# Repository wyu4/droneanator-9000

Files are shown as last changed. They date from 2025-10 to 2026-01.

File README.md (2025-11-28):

# Droneanator 9000

The "Droneanator 9000" is an autonomous unmanned aerial vehicle (UAV). It will aid remote communities worldwide through long-range autonomous supply missions, improving quality of life for those living in these communities. Our clients will include disaster relief agencies, charity organisations, government agencies, etc. See the HRS document for more information.

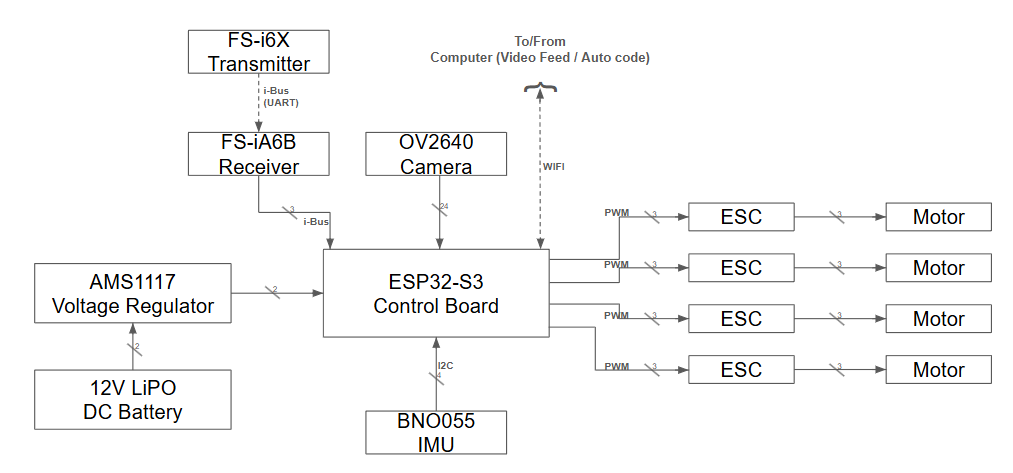
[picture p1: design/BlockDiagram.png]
block diagram


## IDE

This project uses the PlatformIO extension in VSCode.

## Libraries

| **Name** | **Link** |
| --- | --- |
| IBusBM | https://github.com/bmellink/IBusBM |
| BNO055 | https://github.com/adafruit/Adafruit_BNO055 |

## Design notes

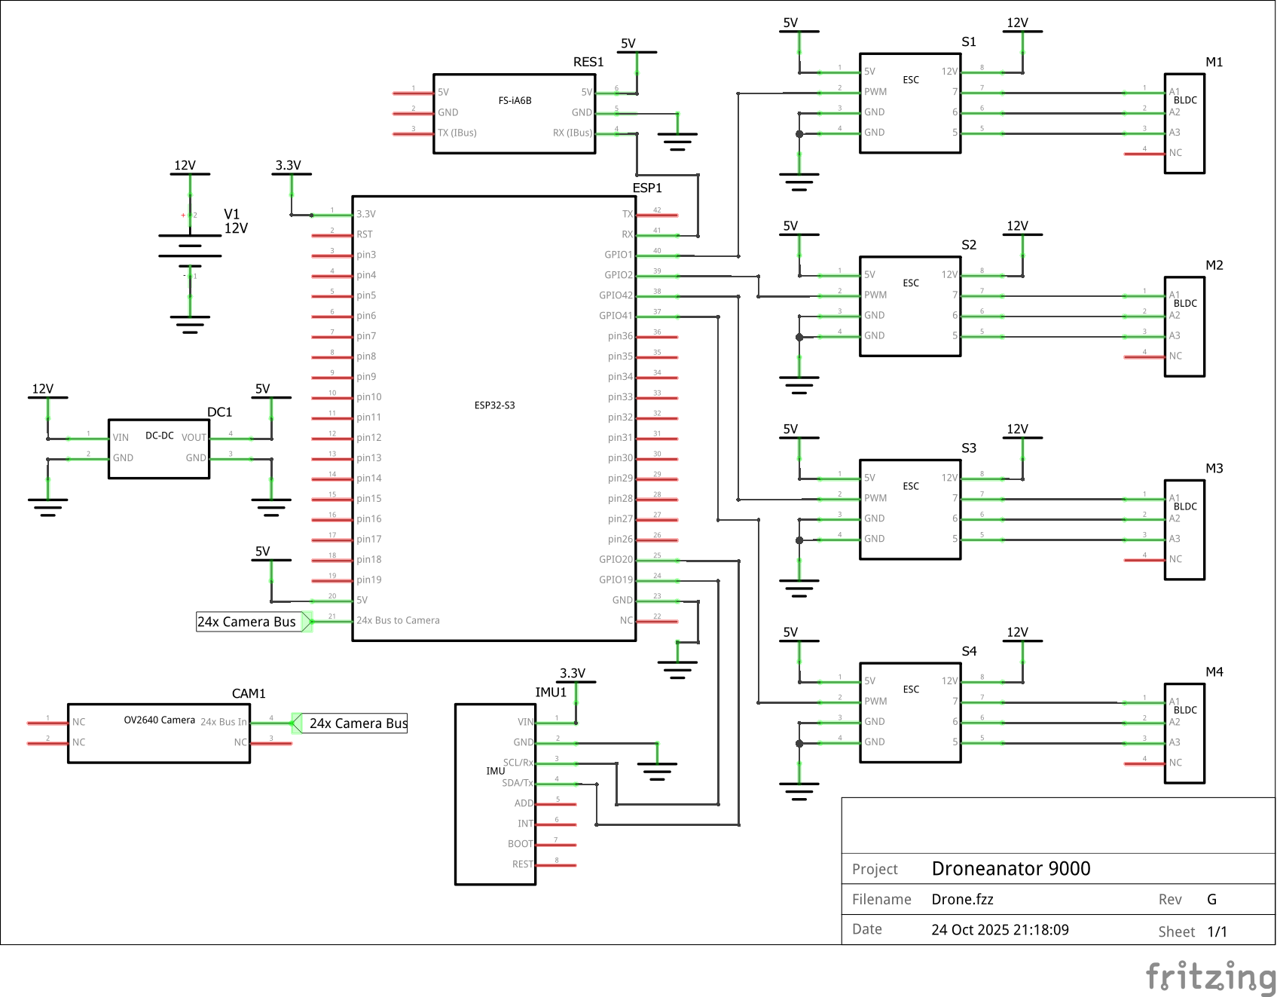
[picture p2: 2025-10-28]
design/DroneV7_schem.png

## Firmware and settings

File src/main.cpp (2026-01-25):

#include <Arduino.h>
#include "Telemetry/Logger.h"
#include "Receiver/Receiver.h"
#include "IMU/IMU.h"
#include "Motor/MotorController.h"
#include "FeedbackLoop/PID.h"

/**
 * @brief Maps any numerical value to a range
 *
 */
#define mapNumber(input, min, max, outMin, outMax) ((input - min) / (max - min) * (outMax - outMin) + outMin);

const boolean hoverOnly = false;
const float maxThrottle = 1800; // MicrosecondsP

MotorController motor1(41, 1); // Front right (clockwise)
MotorController motor2(1, 2);  // Back right (counter-clockwise)
MotorController motor3(42, 3); // Back left (clockwise)
MotorController motor4(2, 4);  // Front left (counter-clockwise)
int output1 = 0;
int output2 = 0;
int output3 = 0;
int output4 = 0;

PID pitchController(1.6, 0.25, 0.8);
PID rollController(1.6, 0.25, 0.8);
PID yawController(6, 0, 0);
// PID rollController(15, 0, 0);
// PID yawController(9, 0, 0);
float pidPitchOutput = 0;
float pidYawOutput = 0;
float pidRollOutput = 0;
unsigned long lastTime = 0;					// Time since boot in microseconds
unsigned long lastTimeTelemetry = 0;		// Time since last telemetry send in microseconds
unsigned long deltaTime = 1;				// Time in microseconds
const unsigned long telemetryRate = 50000; // Time between each telemetry send in microseconds

float desiredThrottle = 0;
float desiredRoll = 0;
float desiredPitch = 0;
float desiredYawVelocity = 0;
int desiredArm = 0;

imu::Quaternion measuredQuaternion(1, 0, 0, 0);
imu::Vector<3> measuredEuler(0, 0, 0);
float rawAxisReadings[] = {0, 0, 0};
float measuredRoll = 0;
float measuredPitch = 0;

// Yaw velocity determined from an averaged circular buffer
const int yawBufferSize = 40;
float measuredYawVelocities[yawBufferSize];
float sumYawVelocities = 0;
float averageYawVelocities = 0;
unsigned int yawBufferCounter = 0;
unsigned int yawBufferIndex = 0;

bool preventThrottle = true;
bool disarmed = false;

/**
 * @brief Stop all motors
 *
 */
void stop()
{
	motor1.stop();
	motor2.stop();
	motor3.stop();
	motor4.stop();
	pitchController.reset();
	rollController.reset();
	yawController.reset();
	output1 = 1000;
	output2 = 1000;
	output3 = 1000;
	output4 = 1000;
	pidPitchOutput = 0;
	pidYawOutput = 0;
	pidRollOutput = 0;
}

/**
 * @brief Send telemetry data over WiFi
 *
 * @param currentTime Current time since boot
 */
void sendTelemetry(const unsigned long &currentTime)
{
	if ((currentTime - lastTimeTelemetry) < telemetryRate)
		return;
	writeUDPF("$data %d %d %d %d %d %0.2f %0.2f %0.2f %0.3f %0.2f %0.2f %0.2f %0.2f %d %0.2f %0.2f %0.2f %d %d %0.2f", output1, output2, output3, output4, hoverOnly, pidPitchOutput, pidRollOutput, pidYawOutput, (deltaTime / 1000.0F), desiredThrottle, desiredPitch, desiredRoll, desiredYawVelocity, desiredArm, measuredPitch, measuredRoll, averageYawVelocities, preventThrottle, disarmed, (currentTime / 1000000.0F));
	lastTimeTelemetry = currentTime;
}

void setup()
{
	stop();

	setupLogger();
	setPairingMode(true);

	Serial.println("Setting up receiver...");
	setupReceiver();
	Serial.println(">>> Successfully set up receiver.");

	Serial.println("Setting up IMU...");
	if (!setupIMU())
	{
		while (true)
		{
			Serial.println(">> Could not set up IMU. Please reboot.");
			delay(1000);
		}
	}
	else
	{
		Serial.println(">> Successfully set up IMU...");
		calibrateIMU();
	}

	Serial.println("Setting up motor controllers...");

	// pitchController.errorSumClamp = 400;
	// rollController.errorSumClamp = 400;
	// yawController.errorSumClamp = 400;          

	delay(1000);
	Serial.println(">> Successfully set up motor controllers...");
}

/**
 * Code that handles reading user input & motor output
 */
void droneLoop() 
{
	if (readChannel(0) < CONTROLLER_MIN_RATE)
	{
		stop();
		Serial.println("Waiting for valid controller value.");
		delay(100);
		return;
	}

	desiredThrottle = mapNumber(readChannel(THROTTLE_CHANNEL), 1000, 2000, 1000, maxThrottle);
	desiredArm = readChannel(ARM_CHANNEL);

	if (!hoverOnly)
	{
		desiredRoll = mapNumber(readChannel(ROLL_CHANNEL), 1000, 2000, -10, 10);
		desiredPitch = mapNumber(readChannel(PITCH_CHANNEL), 1000, 2000, -10, 10);
		desiredYawVelocity = mapNumber(readChannel(YAW_CHANNEL), 1000, 2000, -30, 30);
	}

	if (desiredArm > CONTROLLER_MIN_RATE + 10)
	{
		disarmed = true;
		stop();
		return;
	}

	// This check makes it so that as soon as the drone is re-armed, the user will have to lower the throttle stick first before it does anything
	if (disarmed == true)
	{
		disarmed = false;
		preventThrottle = true;
		return;
	}

	if (preventThrottle)
	{
		stop();
		if (desiredThrottle > CONTROLLER_MIN_RATE + 50)
		{
			Serial.println("Please set the throttle stick to the lowest position.");
			return;
		}
		preventThrottle = false;
	}

	if (desiredThrottle < CONTROLLER_MIN_RATE + 50)
	{
		stop();
		return;
	}

	// Make sure motors stop (ignoring PID controllers) when throttle is at a low state or arming is toggled off

	pitchController.setpoint = desiredPitch;
	rollController.setpoint = desiredRoll;
	yawController.setpoint = desiredYawVelocity;

	pidPitchOutput = pitchController.calculate(measuredPitch, deltaTime / 1000000.0);
	pidYawOutput = yawController.calculate(averageYawVelocities, deltaTime / 1000000.0);
	pidRollOutput = rollController.calculate(measuredRoll, deltaTime / 1000000.0);

	output1 = (int)round(desiredThrottle - pidRollOutput - pidPitchOutput + pidYawOutput); // FR CW
	output2 = (int)round(desiredThrottle - pidRollOutput + pidPitchOutput - pidYawOutput); // BR CCW
	output3 = (int)round(desiredThrottle + pidRollOutput + pidPitchOutput + pidYawOutput); // BL CW
	output4 = (int)round(desiredThrottle + pidRollOutput - pidPitchOutput - pidYawOutput); // FL CCW

	motor1.set(output1);
	motor2.set(output2);
	motor3.set(output3);
	motor4.set(output4);
}

void loop()
{
	const unsigned long currentTime = micros();
	deltaTime = currentTime - lastTime;
	if (deltaTime == 0)
		deltaTime = 1;
	if (lastTime == 0)
	{ // If lastTime is invalid
		lastTime = currentTime;
		stop();
		return;
	}
	lastTime = currentTime;

	updateReceiver();

	getRawAxis(rawAxisReadings);

	measuredRoll = rawAxisReadings[1];
	measuredPitch = -rawAxisReadings[2];

	// Handling average yaw velocities
	sumYawVelocities -= measuredYawVelocities[yawBufferIndex];
	measuredYawVelocities[yawBufferIndex] = rawAxisReadings[0];
	sumYawVelocities += rawAxisReadings[0];

	yawBufferIndex = (yawBufferIndex + 1) % yawBufferSize; // Wrapping the selected index

	if (yawBufferCounter < yawBufferSize - 1) // Making sure loop runs enough time to have enough data
	{
		stop();
		
		yawBufferCounter += 1;
		delay(10); // BNO055 outputs 100 samples/second
		return;
	};

	averageYawVelocities = sumYawVelocities / yawBufferSize;

	droneLoop();
	
	sendTelemetry(currentTime);
}

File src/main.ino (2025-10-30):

#include <Arduino.h>
#include "Telemetry/Logger.h"
#include "Receiver/Receiver.h"
#include "Motor/MotorController.h"

TaskHandle_t TelemetryTaskHandle = NULL;

/**
 * @brief The telemetry thread. This is completely cut off from the main thread to minimize stalling on the flight-controller's main functions
 *
 * @param parameter
 */
void TelemetryTask(void *parameter)
{
  for (;;)
  {
    updateLogger();
  }
}

void setup()
{
  setupLogger();

  print("Setting up receiver...\n");
  setupReceiver();
  print(">>> Successfully set up receiver.\n");

  print("Setting up motor controllers...\n");
  setupMotorControllers();

  xTaskCreatePinnedToCore(
      TelemetryTask,        // Task function
      "TelemetryTask",      // Task name
      10000,                // Stack size (bytes)
      NULL,                 // Parameters
      2,                    // Priority
      &TelemetryTaskHandle, // Task handle
      2                     // Core
  );
}

void loop()
{
}

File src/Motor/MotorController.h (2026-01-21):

#include <Arduino.h>

const int MOTOR_FREQUENCY = 50; // Hz
const int MOTOR_RESOLUTION = 11; // Bits
const int PWM_MIN = 1000;              // Minimum pulse width in microseconds
const int PWM_MAX = 2000;           // Maximum pulse width in microseconds

/**
 * @brief The Motor Controller class.
 *
 */
struct MotorController
{
    /**
     * @brief The configured channel for the motor controller
     *
     */
    const uint8_t channel;

    /**
     * @brief Construct a new Motor Controller object
     *
     * @param pin The PWM pin connected to the motor controller
     * @param channel The channel
     */
    MotorController(const uint8_t pin, const uint8_t channel);

    /**
     * @brief Set the pulse width of the PWM going to the motor controller
     *
     * @param value Pulse width in microseconds
     */
    void set(int value);

    /**
     * @brief Stops the motor
     * 
     */
    void stop();
};

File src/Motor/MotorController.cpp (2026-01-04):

#include "MotorController.h"

const int MAX_DUTY = pow(2, MOTOR_RESOLUTION) - 1; // Biggest (unsigned) number given the resolution
const int PERIOD = (1.0F/MOTOR_FREQUENCY) * 1000000; // Time it takes to compelte one PWM cycle in microseconds

MotorController::MotorController(const uint8_t pin, const uint8_t channel) : channel(channel)
{
    ledcSetup(channel, MOTOR_FREQUENCY, MOTOR_RESOLUTION);
    ledcAttachPin(pin, channel);
}

void MotorController::set(int pulseWidth)
{
    int clamped = constrain(pulseWidth, PWM_MIN, PWM_MAX);
    int output = ((clamped * MAX_DUTY) / PERIOD); // Mathematically: calculated duty cycle as decimal, and multiplies by max duty
    ledcWrite(this->channel, output);
}

void MotorController::stop()
{
    this->set(1000);
}

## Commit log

2025-10-30 Add second thread for telemetry + Sendign strings over UDP
2025-10-30 Move telemetry thread to core 0
2025-11-03 Use the correct printformat
    [main.cpp]
2025-11-04 Adjust PWM valuse + fix controller channels
    [MotorController.h, Receiver.h, main.cpp]
2025-11-04 Potentially corrected PWM values
    [MotorController.cpp, MotorController.h]
2025-11-05 Working motor code
2025-11-05 Lower max PWM value to 2000
2025-11-13 Create IMU and PID controllers
2025-11-21 Create working IMU code
2025-11-24 Set up PID controllers with desired values and measured values
2025-12-02 fixed motor pins and upped PID values
    [main.cpp]
2025-12-04 PID testing with wyu
2025-12-04 Make desired yaw additive
2025-12-08 added arm switch stuff, doesnt work :)
2025-12-10 Move arming logic
    Arming boolean check is moved into the same if statement as the throttle check
2025-12-10 Use microseconds + Set desired yaw to measured yaw when drone not active
2025-12-11 Reset PID values
2025-12-12 Fix pid axis being applied to wrong output axis
    [main.cpp]
2025-12-12 Correct motor pins
2025-12-16 [UNTESTED] Use yaw velocity instead of absolute measure
2025-12-16 Revert "[UNTESTED] Use yaw velocity instead of absolute measure"
    This reverts commit d99fea31475b0521a64dfcb32d94742c3990fe7d.
    [Logger.cpp, main.cpp]
2025-12-18 Reapply "[UNTESTED] Use yaw velocity instead of absolute measure"
    This reverts commit 91a3978f9ccee08031914202e0e52350e7cb722e.
    [Logger.cpp, main.cpp]
2025-12-18 Read yaw velocity from register instead of quaternion
2025-12-18 Set yaw output instead of adding to it
    I misunderstood the physics...
2026-01-04 Use LEDC instead of analogWrite
2026-01-04 Fix motor1 overlapping with TX
    [MotorController.cpp, MotorController.h, main.cpp]
2026-01-04 Adjust yaw P value
2026-01-05 Improve receiver code + Prep for IMU axis usage
2026-01-05 Create working telemetry
    There's a bug where the connection is silently severred after a couple seconds
    [Logger.cpp, main.cpp]
2026-01-06 Fix yaw axis
2026-01-07 Use average yaw velocity
    Eliminates so much noise, sample size is changeable and stored in the variable 'yawBufferSize'
    [Logger.cpp, main.cpp]
2026-01-07 Start PID tuning with pole setup
2026-01-08 pid is poo but P is less bad, still need D and a lot of I
2026-01-23 Set errorSum to double
    [main.cpp]
2026-01-25 Change PID to use seconds instead of milliseconds
